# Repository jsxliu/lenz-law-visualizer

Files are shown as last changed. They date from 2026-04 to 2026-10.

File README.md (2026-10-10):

# Lenz’s Law Visualizers

**An open-source hardware initiative by [OpenApparatus](https://openapparatus.org/)**

Three classroom designs demonstrate eddy currents and magnetic braking. Each
includes printable parts, a materials list, photographs, physics-based animation, and assembly instructions.

## Choose a design

| Design | Published version | Description | Build guide and files |
| --- | --- | --- | --- |
| Dual-tube | v1 | Compare a magnet descending through copper tube with a control weight falling through a clear tube. | [View dual-tube design](designs/dual-tube-design/README.md) |
| Triple-tube | v1 | Compare a control weight in a clear tube with magnets descending through aluminum and copper tubes; the control falls fastest and the copper-tube magnet slowest. | [View triple-tube design](designs/triple-tube-design/README.md) |
| See-through | v1 | Watch a ring magnet and a nonmagnetic control ring descend around matching copper tubes inside clear tubes, making magnetic braking directly visible. | [View see-through design](designs/see-through-design/README.md) |

### Dual-tube visualizer

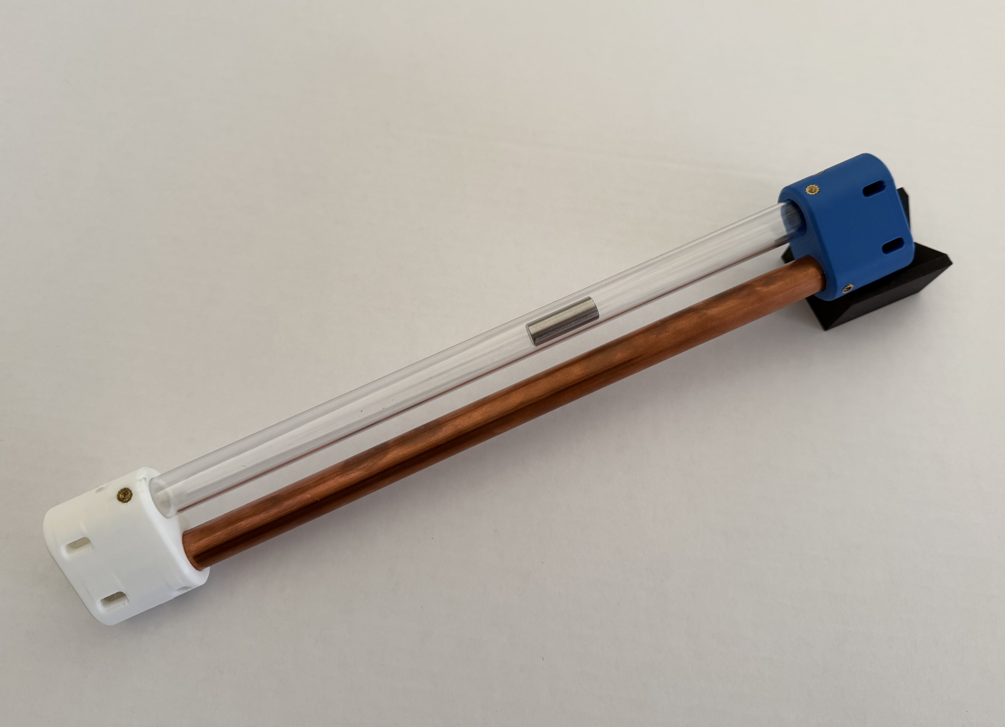
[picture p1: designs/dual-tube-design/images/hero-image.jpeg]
Dual-tube prototype


[Build guide and print files](designs/dual-tube-design/README.md).
Compares a magnet falling through a copper tube with a nonmagnetic control weight falling through a clear tube.

[Watch the animation (22.5 seconds)](https://jsxliu.github.io/lenz-law-visualizer/designs/dual-tube-design/animation/):
a real-time fall followed by a quarter-speed slow-motion replay.
The player includes a **Download video (MP4)** link.
See the [animation notes](designs/dual-tube-design/animation/README.md)
for its parameters, assumptions, and credits.

### Triple-tube visualizer

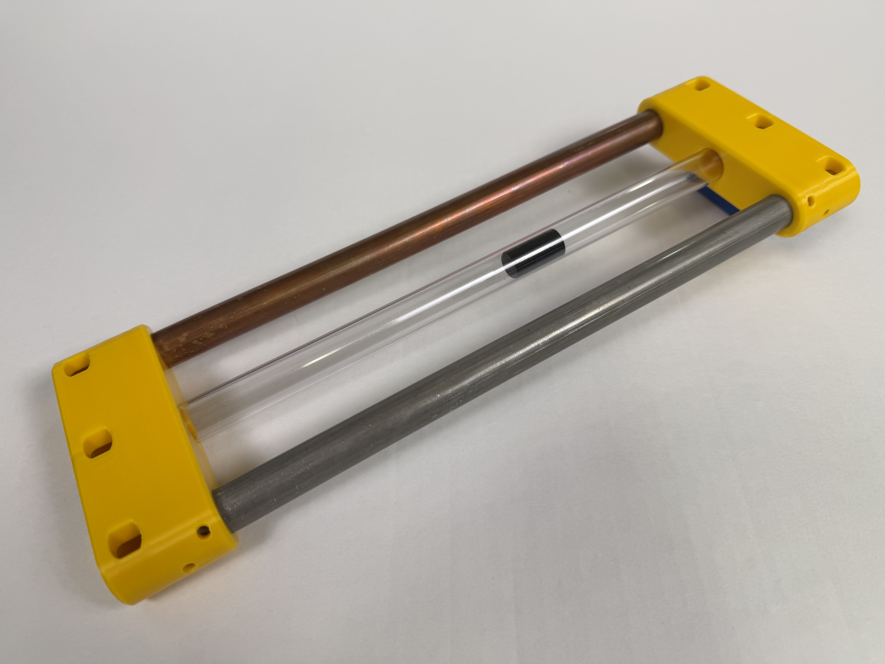
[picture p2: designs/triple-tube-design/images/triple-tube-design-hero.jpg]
Triple-tube prototype


[Build guide and print files](designs/triple-tube-design/README.md).
Adds an aluminum tube for comparison with the copper and clear tubes.

[Watch the animation (20.72 seconds)](https://jsxliu.github.io/lenz-law-visualizer/designs/triple-tube-design/animation/):
a simultaneous release in copper, clear, and aluminum tubes, followed by a
quarter-speed replay. The player includes a **Download video (MP4)** link.
See the [animation notes](designs/triple-tube-design/animation/README.md)
for its parameters, assumptions, and credits.

### See-through visualizer

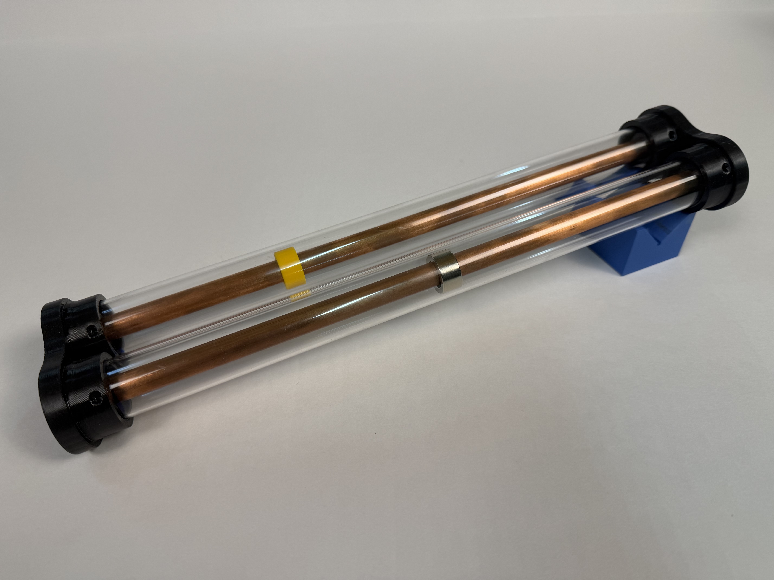
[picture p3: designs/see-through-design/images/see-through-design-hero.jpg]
See-through prototype


[Build guide and print files](designs/see-through-design/README.md).
Clear outer tubes keep the ring magnet and control ring enclosed and visible throughout their falls.

[Watch the animation (12.05 seconds)](https://jsxliu.github.io/lenz-law-visualizer/designs/see-through-design/animation/):
a real-time fall followed by a quarter-speed slow-motion replay.
The player includes a **Download video (MP4)** link.
See the [animation notes](designs/see-through-design/animation/README.md)
for its parameters, assumptions, and credits.

## Repository layout

```text
README.md                       Overview and design comparison
CITATION.cff                   Citation metadata for GitHub
LICENSE                         Shared hardware license
designs/
   dual-tube-design/
     README.md                  Existing design’s build guide
     animation/                 Video player, scenario, and credits
     parts/                     Printable STL files
     images/                    Prototype photograph
   triple-tube-design/
     README.md                  v1 build guide
     animation/                 Video player, scenario, and credits
     parts/                     Printable STL files
     images/                    Prototype photograph
   see-through-design/
     README.md                  v1 build guide
     animation/                 Video player, scenario, and credits
     parts/                     Printable STL files
     images/                    Prototype photograph
```

## Citation

Use GitHub’s **Cite this repository** menu or [CITATION.cff](CITATION.cff).
Include the design and version when citing a particular build, such as **Dual-Tube Design, v1**.

Suggested general citation:

> Liu, Jonathan. *Lenz’s Law Visualizers*. OpenApparatus, 2026. [https://github.com/jsxliu/lenz-law-visualizer](https://github.com/jsxliu/lenz-law-visualizer).

## License and attribution

- Hardware designs and build documentation: [CERN-OHL-W-2.0](LICENSE).
- Animation text, video, poster, and synthesized sound: [CC BY 4.0](designs/dual-tube-design/animation/LICENSE-media).
- Animation viewer: [MIT](designs/dual-tube-design/animation/LICENSE-viewer).

See the [dual-tube animation credits](designs/dual-tube-design/animation/credits.md),
[triple-tube animation credits](designs/triple-tube-design/animation/credits.md),
and [see-through animation credits](designs/see-through-design/animation/credits.md) for sources and attribution.

Created by Jonathan Liu. If you build from or adapt this project, please preserve attribution and clearly indicate your modifications.

## Community acknowledgements

Thank you to educators who tested beta builds, built their own versions, and
shared feedback, and to participants at Maker Faires, FAB26 in Boston, and
classroom and university mini-workshops. Their experiences help improve these designs.

## AI assistance

AI tools assisted with drafting documentation, refactoring code, and creating visuals. Jonathan Liu at OpenApparatus directs the project and retains responsibility for design decisions, physical testing, and published content.

## Get involved with OpenApparatus

* **Educators:** [Request a Beta-Test Donation](https://openapparatus.org/beta.html).
* **Students:** [Apply to Start a Chapter](https://forms.gle/mwWGrnZB5XusfW3L9).
* **Learn more:** Visit [openapparatus.org](https://openapparatus.org/).

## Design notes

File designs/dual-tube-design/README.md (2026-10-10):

# Dual-Tube Lenz's Law Visualizer

**An open-source hardware initiative by [OpenApparatus](https://openapparatus.org/)**

[← All designs](../../README.md)

**Status:** Public prototype · **Design version:** v1

As of September 2026, 20 beta units have been deployed to universities,
museums, and high schools across 13 states and 3 countries. Testing
includes a [4,000-cycle automated stress test](https://www.youtube.com/watch?v=3sY6RCX2NQ0)
using a motorized, Arduino-controlled rig.

A ruggedized, student-built, and user-friendly physics apparatus designed to safely visualize eddy currents and magnetic braking in a classroom setting.

When a permanent rare-earth magnet falls through the copper tube, the changing magnetic field induces massive eddy currents in the conductive wall through a small air gap. This creates an opposing magnetic force that acts as an "invisible parachute" or "invisible brake." Simultaneously, a non-magnetic control weight free-falls through a parallel clear polycarbonate tube, providing a real-time contrast in velocity. Builders can use either the original off-the-shelf 316 stainless steel dowel pin or the included 3D-printable control weight.

The control weight reaches the opposite end almost instantly, while the magnet's soft landing is dramatically delayed by several seconds due to the magnetic braking effect. Both descents can be confirmed visually through the 3D-printed slotted viewing windows, with the clear tube offering full visual acuity of the free-fall baseline.

Built entirely from easily sourced off-the-shelf hardware and two custom 3D-printed end caps, this kit is perfect for high school physics demonstrations, hands-on STEM outreach, electromagnetic modeling, and kinematics calculations.

I built this project as a high school junior to deepen my understanding of physics, practice hands-on design, and develop a clear way to communicate scientific ideas through hardware.

Prototype image

## Physics-based animation

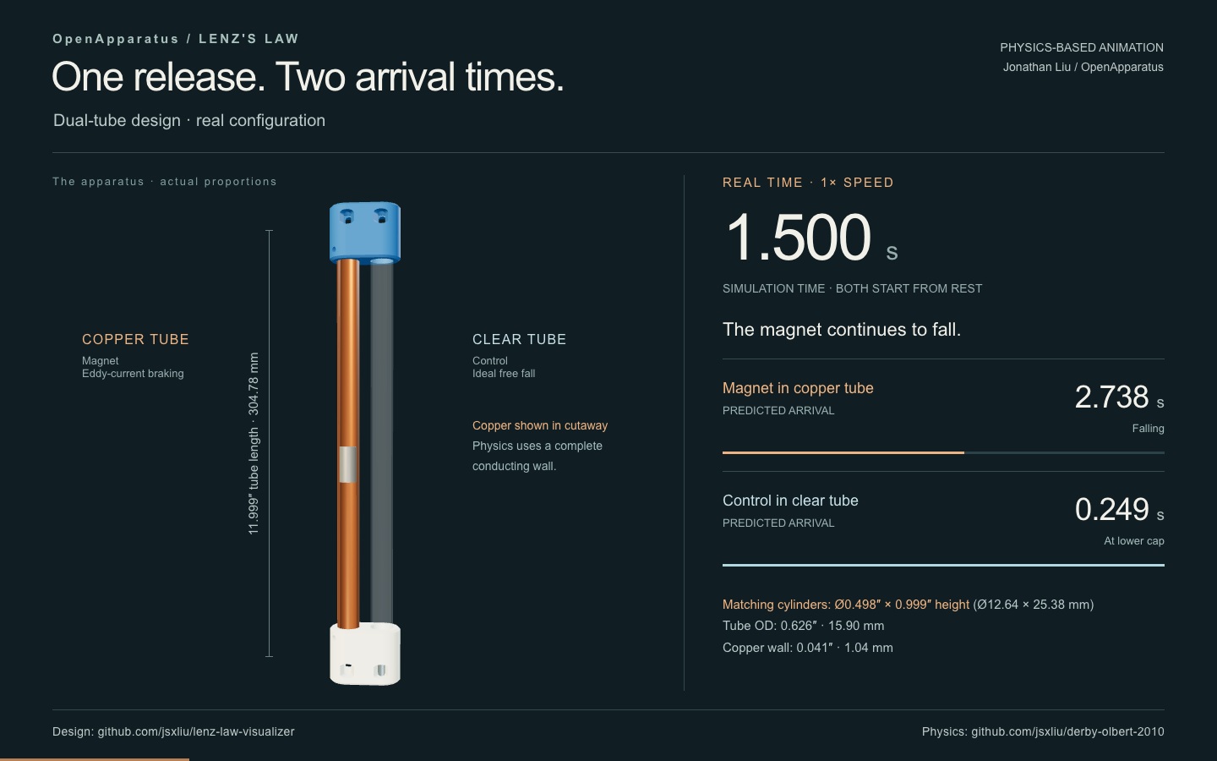
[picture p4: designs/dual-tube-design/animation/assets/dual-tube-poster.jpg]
Preview of the dual-tube physics-based animation


**[Watch the animation (22.5 seconds)](https://jsxliu.github.io/lenz-law-visualizer/designs/dual-tube-design/animation/)**

The player includes a **Download video (MP4)** link.

This fixed simulation serves as a first-order digital twin, showing a real-time
fall and quarter-speed replay. Calculations use the
[Derby–Olbert reproduction](https://github.com/jsxliu/derby-olbert-2010).
Predicted arrivals are **2.738 s** for the magnet and **0.249 s** for the control.
The copper cutaway is visual only; the modeled wall remains electrically intact.

The film represents one configuration; hardware dimensions and results can vary.
See its [parameters and assumptions](animation/scenario.md) and
[credits and licenses](animation/credits.md).

## Print files

* [cap_lenz_visualizer_v2.stl](parts/cap_lenz_visualizer_v2.stl) — 3D-printable end cap; print two
* [control_weight_cylinder_3D_print_v1.stl](parts/control_weight_cylinder_3D_print_v1.stl) — Optional 3D-printable control weight; print one

## Safety

* **Captive System:** The end caps and fasteners keep the magnet and control weight enclosed, reducing shatter, impact, and pinch hazards. Inspect the caps, tubes, inserts, and fasteners before every demonstration, and do not use the apparatus if any part is cracked, loose, or damaged.
* **Strong Magnets:** Keep the apparatus away from implanted medical devices, magnetic storage, electronics, and ferromagnetic objects. Follow the magnet manufacturer’s handling and separation guidance.
* **Pinch, Impact, and Shatter Hazards:** Keep fingers and loose metal objects away from the magnet. Do not use a cracked or chipped magnet.
* **Hot Surfaces & Sharp Edges:** Assembly requires a soldering iron and mechanical cutting tools. Wear appropriate protection and handle hot tools and metal edges carefully.
* **Supervision:** Assemble and operate the apparatus under qualified adult supervision.

## Bill of materials (per kit)

**Hardware:**

* 1x Copper Tube: Nominal 1/2-inch Type L or Type M, with a 5/8-inch outside diameter, cut to 12 inches. See the [Copper Tube Handbook](https://www.copper.org/publications/pub_list/pdf/copper_tube_handbook.pdf) for standard dimensions.
* 1x Clear Tube: Polycarbonate, 5/8" OD x 1/2" ID x 1/16" Wall, cut to 12 inches.
* 1x Magnet: Neodymium Cylinder, 1/2" Nominal Diameter x 1.00" Height.
* 1x Control Weight — choose one option:
  * **Off-the-shelf:** 316 stainless steel dowel pin matching the nominal size of the magnet.
  * **3D-printed:** Print [control_weight_cylinder_3D_print_v1.stl](parts/control_weight_cylinder_3D_print_v1.stl).

**Fasteners (For 2 End Caps):**

* 6x Ruthex M3 Threaded Inserts (RX-M3x5x4 Brass Heat-Set).
* 6x M3-0.5 x 5mm Hex Socket Set Screws (Cup Point).

**3D-Printed Parts:**

* 2x End Caps: Print [cap_lenz_visualizer_v2.stl](parts/cap_lenz_visualizer_v2.stl).
* 1x Control Weight (optional): Print [control_weight_cylinder_3D_print_v1.stl](parts/control_weight_cylinder_3D_print_v1.stl) instead of using the stainless steel dowel pin.

## Print settings (PETG recommended)

**End Caps:**

* **Wall loops:** 6.
* **Strength - Sparse Infill:** 18% density, gyroid pattern.

**3D-Printed Control Weight:**

* **Strength - Sparse Infill Density:** 100%.
* **Strength - Sparse Infill Pattern:** Rectilinear.

## Assembly

**Required Tools & Accessories:**

* Tubing Cutter (Suitable for copper and plastic)
* Reaming Pen / Deburring Tool
* Soldering Iron for Heat-Set Inserts
* Loctite 242 (Blue Removable Threadlocker)
* Metric Hex Key (For M3 set screws)
* Caliper and Tape Measure

**Assembly Steps:**

1. **Prepare the Tubes:** Cut both the copper and polycarbonate tubes to exactly 12 inches in length. Use the reaming pen to thoroughly deburr the inside and outside edges of all cut ends.
2. **Check Free Travel:** Over a padded surface, pass the magnet through the copper tube and the selected control weight through the clear tube. Confirm that both objects travel from end to end without binding.
3. **Install the Inserts:** Temporarily seat the copper tube in its socket so it acts as a depth stop for the adjacent inserts. Using the soldering iron, gently heat-set three brass inserts into each end cap until they are flush with the plastic. Keep the inserts perpendicular to the cap surface, use the correct tool temperature for the selected filament, and remove the temporary tube after the inserts and surrounding plastic have cooled completely.
4. **Seat the Tubes:** Insert the copper and polycarbonate tubes into the bottom end cap until both meet their internal stops. The cavities are asymmetric to account for material tolerances: the copper tube seats in the tighter cavity and the polycarbonate tube in the looser cavity. Do not force the polycarbonate tube into the tighter cavity.
5. **Load the Weights:** Place the permanent magnet in the copper tube and the selected control weight—the stainless steel dowel pin or the 3D-printed cylinder—in the polycarbonate tube. Use one control-weight option, not both.
6. **Cap the System:** Align the asymmetric sockets and press the second end cap fully onto both tubes. Do not invert the apparatus until both caps have been fastened.
7. **Secure the Assembly:** Install three set screws in each end cap against the copper tube. Apply a small amount of Loctite 242 to the screw threads and tighten the screws evenly until snug. Do not overtighten or deform the copper tube. No set screws should contact the polycarbonate tube.
8. **Allow the Threadlocker to Cure:** Leave the assembly undisturbed for at least 24 hours at room temperature, or longer if required by the threadlocker manufacturer for the working conditions.
9. **Inspect the Captive System:** Confirm that all six set screws are secure, both caps are fully seated, and neither falling object can leave the apparatus.
10. **Perform the Function Check:** Over a padded surface, flip the secured apparatus several times. Confirm that the magnet and control weight travel from end to end without binding.

## Version

* **v1** — Initial public prototype release, as documented in the original README.

The existing end-cap STL filename includes `v2` and has been preserved for traceability. The printable control-weight STL was added as an alternative to the original off-the-shelf stainless steel dowel pin. These file changes do not establish a new hardware revision.

## License and attribution

The hardware design and this build guide retain the **CERN Open Hardware
Licence Version 2 - Weakly Reciprocal (CERN-OHL-W-2.0)**. See the
[repository LICENSE](../../LICENSE) for the full license text.

The animation's original text, video, poster, and synthesized sound are licensed
under [CC BY 4.0](animation/LICENSE-media); its HTML/CSS viewer is
[MIT licensed](animation/LICENSE-viewer).
See the [component credits](animation/credits.md).

Created by Jonathan Liu. If you build from or adapt this project, please preserve attribution and clearly indicate your modifications.

## 📝 Notes
This repository is meant to document an authentic learning and design process. The project may evolve over time as testing, classroom use, and fabrication experience lead to improvements.

## 🌍 Get Involved with OpenApparatus

This repository is maintained by the **OpenApparatus** engineering team. We are dedicated to removing the financial barriers to advanced physics and engineering education.

* **Educators:** Want to deploy this hardware in your classroom? [Request a Beta-Test Donation](https://openapparatus.org/beta.html).
* **Students:** Want to manufacture these kits for underfunded schools in your area? [Apply to Start a Chapter](https://forms.gle/mwWGrnZB5XusfW3L9).
* **Learn More:** Visit [openapparatus.org](https://openapparatus.org/) to see our full library of open-source STEM modules and our latest deployment impact metrics.

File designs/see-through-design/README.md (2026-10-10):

# See-Through Lenz’s Law Visualizer

**An open-source hardware initiative by [OpenApparatus](https://openapparatus.org/)**

[← All designs](../../README.md)

The see-through visualizer makes magnetic braking directly visible. A ring magnet falls around a copper tube, enclosed by a clear polycarbonate tube.

Two parallel drop paths use matching copper and polycarbonate tubes. One contains the ring magnet; the other contains a nonmagnetic, 3D-printed control weight with the same ring geometry.

The moving magnet induces eddy currents in the copper wall. Their magnetic field opposes its motion, slowing its descent. The printed ring provides a free-fall reference, and both descents remain visible through the clear tubes.

Two 3D-printed end caps hold the tubes. Epoxy bonds the polycarbonate tubes to the caps; the copper tubes sit in unbonded sockets.

See-through prototype

## Physics-based animation

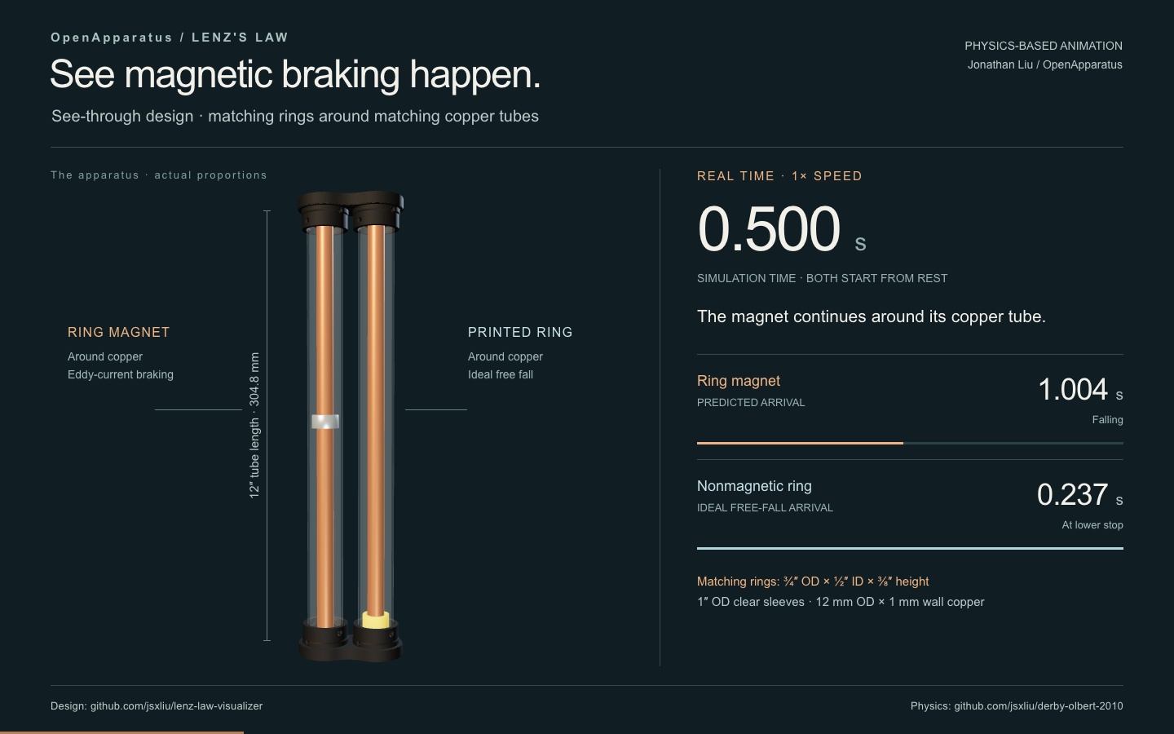
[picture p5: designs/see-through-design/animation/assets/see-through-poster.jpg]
Preview of the see-through physics-based animation


**[Watch the animation (12.05 seconds)](https://jsxliu.github.io/lenz-law-visualizer/designs/see-through-design/animation/)**

The player includes a **Download video (MP4)** link.

The existing-size ring magnet and matching nonmagnetic control are released
simultaneously, shown at real time and replayed at quarter speed. Predicted
arrivals are **1.004 s** for the magnet and **0.237 s** for the control. The simulation adapts
the cylindrical-magnet field from the
[Derby–Olbert reproduction](https://github.com/jsxliu/derby-olbert-2010)
to the ring geometry; the control follows analytic free fall.

See the [parameters and assumptions](animation/scenario.md) and
[credits and licenses](animation/credits.md).

## 📁 Overview

This folder contains the prototype photograph, two printable STL files, a physics-based animation, and build guidance for the see-through design.

**Included files:**

* [animation/](animation/README.md) — Video player, MP4, scenario, and credits

* [see-through-design-hero.jpg](images/see-through-design-hero.jpg) — Prototype photograph
* [see_through_design_end_cap_v1.stl](parts/see_through_design_end_cap_v1.stl) — See-through end cap; print two
* [free_fall_ring_v1.stl](parts/free_fall_ring_v1.stl) — Ring-shaped control weight; print one
* `README.md` — Project overview, safety notes, and build guidance

## 💡 Motivation

I enjoy building physical models that make abstract science ideas easier to see and explain. This project combines physics, mechanical design, 3D printing, and technical communication. The see-through variation addresses the limited visibility of a magnet inside an opaque conducting tube by moving a ring magnet around the outside of the conductor.

## ⚠️ Safety & Liability

* **Captive system:** The end caps and cured adhesive joints keep the falling objects enclosed. Inspect the caps, tubes, and adhesive joints before every demonstration. Do not use the apparatus if any part is cracked, loose, displaced, or damaged.
* **Strong magnets:** Keep the apparatus away from implanted medical devices, magnetic storage, electronics, and ferromagnetic objects. Follow the magnet manufacturer’s handling and separation guidance.
* **Adhesives and chemical exposure:** Avoid skin and eye contact with uncured resin, hardener, and mixed epoxy. Wear gloves compatible with the selected product, safety goggles, and protective clothing. Perform syringe injection in a well-lit, well-ventilated workspace with a protected work surface, separated from bystanders. Follow the product’s Safety Data Sheet for handling, cleanup, disposal, and first aid.
* **Supervision:** Assemble and operate the apparatus under qualified adult supervision.

## 🛠️ Bill of Materials (Per Kit)

### Hardware

* 2x Inner Copper Tubes: Matching tubes, each with a 12 mm outside diameter and 1 mm wall thickness (10 mm calculated inside diameter). Choose stock at least as long as the actual polycarbonate tubes, then trim to match their length.
* 2x Outer Clear Tubes: Matching polycarbonate tubes, each with a 0.87-inch inside diameter, 1-inch outside diameter, and nominal 12-inch length. Each surrounds an inner copper tube and a falling ring.
* 1x Magnet: Permanent ring magnet (annular cylinder), with a 1/2-inch inside diameter, 3/4-inch outside diameter, and 3/8- inch height.
* 1x Control Weight: Nonmagnetic, 3D-printed ring cylinder with the same geometry as the magnet: 1/2-inch inside diameter, 3/4-inch outside diameter, and 3/8-inch height.

**Why 12 mm copper OD:** The magnet’s 1/2-inch (12.7-mm) inside diameter limits the copper-tube outside diameter. The selected maximum OD for this design is **12 mm**, leaving 0.7 mm diametral clearance, or a nominal **0.35 mm radial gap** when centered. The magnet’s terminal velocity and resulting drop time depend strongly on this gap. The 12-mm OD keeps the gap small while providing clearance for free sliding.

**Tube lengths:** 12-inch is exactly **304.8-mm**, not 300-mm. Tubes listed online as 300-mm may arrive as exact 12-inch lengths; measure the actual tubes before cutting. Both polycarbonate tubes must have the same length, and both copper tubes must match that measured length. If a copper tube is too short, obtain longer stock.

### Adhesives

* **Epoxy:** [WEST SYSTEM G/flex 650 Toughened Epoxy](https://www.westsystem.com/products/g-flex-650-toughened-epoxy/). Mix resin and hardener thoroughly **1:1 by volume**.
* **Application:** Bond the four polycarbonate-to-end-cap joints. The copper tubes remain seated without adhesive.
* **Cure:** Keep the assembly supported and undisturbed for at least **24 hours at 72°F (22°C)** after the final injection before handling or use. Allow longer cure time in cooler conditions.

Follow the manufacturer’s [application instructions](https://www.westsystem.com/app/uploads/2022/12/650-K-Aluminum-Kit-Instruction.pdf) and [resin and hardener Safety Data Sheets](https://www.westsystem.com/safety/safety-data-sheets/).

### 3D-Printed Parts

* 2x See-Through End Caps: Each locates the two inner copper tubes and two outer polycarbonate tubes and includes the adhesive injection and vent ports. **Print file:** [see_through_design_end_cap_v1.stl](parts/see_through_design_end_cap_v1.stl).
* 1x Ring-Shaped Control Weight: Match the magnet’s inside diameter, outside diameter, and height for a fair comparison. Confirm that the printed ring slides freely around its copper tube and inside its clear tube. **Print file:** [free_fall_ring_v1.stl](parts/free_fall_ring_v1.stl).

## 🖨️ 3D-Printer Settings (PETG Starting Material)

Use these settings as a starting point for the included STL files. Check the printed parts’ fit and the filament’s compatibility with the epoxy before assembly.

**End Caps — Starting Settings:**

* **Strength — Wall Loops:** 6
* **Strength — Sparse Infill:** 18% density, gyroid pattern

**3D-Printed Ring Control Weight:**

* **Strength — Sparse Infill Density:** 100%
* **Strength — Sparse Infill Pattern:** Rectilinear

## ⚙️ Assembly Procedure

**Required Tools & Accessories:**

* Copper tube cutter and, if needed, a cutting tool suitable for polycarbonate
* Reaming pen or deburring tool
* Caliper and tape measure
* Epoxy mixing cups and stirrers
* Glue applicator syringe with a blunt-tip needle, sealing cap, and dispensing tips, used to inject the mixed epoxy into the end-cap ports
* Product-compatible protective gloves, safety goggles, and protective clothing
* Protected work surface and supports that maintain tube and cap alignment during curing

**Assembly Steps:**

1. **Prepare the tubes:** Measure both polycarbonate tubes and confirm they are the same length. Use that actual length as the reference for both copper tubes. If a copper tube is longer, use a copper tube cutter to trim it to match; replace any copper tube that is too short with longer stock. Use a deburring tool to clean the inside and outside edges of cut or rough tube ends as needed, remove debris, and confirm all four tubes have the same final length. Prepare the bonding surfaces according to the adhesive manufacturer’s instructions for each material.
2. **Print and inspect the parts:** Print two end caps and one ring-shaped control weight. Reject parts with cracks, weak layers, obstructed sockets, or malformed injection and vent ports. Remove rough edges and debris from the control weight’s travel surfaces.
3. **Check the individual travel paths:** Slide the ring magnet around one copper tube and the control weight around the other. Check each inside its polycarbonate outer tube. Both rings must travel freely without catching on the copper, clear tube, or end-cap seating surfaces.
4. **Seat the first cap:** Insert both inner copper tubes into their sockets in one end cap. Seat the matching outer polycarbonate tube around each copper tube. Keep each pair concentric and fully seated against its designated stops.
5. **Load the falling objects:** Slide the ring magnet over the copper tube in one path and the printed ring control weight over the copper tube in the other. Keep each object inside its outer polycarbonate tube.
6. **Fit the second cap:** Align the inner and outer sockets and place the second end cap onto all four tubes. Confirm that every tube remains fully seated and that both paths stay aligned.
7. **Perform the initial function check:** With both unbonded caps held together using both hands, gently flip the apparatus several times. Confirm that the magnet and control weight both travel smoothly from end to end.
8. **Prepare for adhesive injection:** Set up the well-lit, well-ventilated workspace, put on the required gloves and goggles, and support the aligned assembly. Identify the injection and vent ports for each local tube-to-cap joint. Prepare and load the epoxy according to its specified mix ratio and working time.
9. **Inject and distribute epoxy at one joint:** Orient the joint so its injection port is below its vent port. Inject slowly through the lower port until epoxy first appears at the upper vent. Stop before excess adhesive enters the falling path. While the epoxy is workable, gently rotate the polycarbonate tube within its socket to help distribute adhesive around the bonding interface, without unseating the tube or disturbing alignment. Rotation helps distribute adhesive; the socket geometry controls the bond gap.
10. **Repeat at the remaining joints:** Repeat the injection and distribution process for the other three outer-polycarbonate-to-cap joints, covering both ends of both clear tubes. Keep all tubes seated. Complete any rotation before the epoxy at either end of that tube begins to set; then leave the tube undisturbed. The inner copper tubes remain captured in their sockets; do not inject adhesive into their seats or the rings’ travel paths.
11. **Allow the adhesive to cure:** Keep the assembly supported and undisturbed for at least 24 hours at 72°F (22°C) after the final injection; allow longer in cooler conditions. Follow the cure guidance in [Adhesives](#adhesives).
12. **Inspect and perform the final function check:** Once full cure is complete, inspect every bond, tube seat, and cap. Confirm that the copper tubes are retained, neither cap can separate during normal operation, and no adhesive obstructs either ring’s travel. Manually turn the completed apparatus over several times and confirm that both objects still travel smoothly.

## 🔬 Use and Expected Observations

Move both falling objects to the same end of the completed apparatus. Turn it over to release them together and observe both rings through the clear polycarbonate tubes.

* **Control path:** The nonmagnetic, printed ring falls quickly, providing the free-fall reference.
* **Magnet path:** The ring magnet falls more slowly because its motion induces eddy currents in the inner copper tube.

Both rings remain visible throughout their descent. Mechanical friction effects are usually negligible in this type of setting and design.

## 📄 License

This project is licensed under the **CERN Open Hardware Licence Version 2 – Weakly Reciprocal (CERN-OHL-W-2.0)**. Please see the [repository LICENSE](../../LICENSE) file for the full license text.

The animation text, video, poster, and synthesized landing sounds use
[CC BY 4.0](animation/LICENSE-media); the viewer uses
[MIT](animation/LICENSE-viewer). See [component credits](animation/credits.md).

## ✍️ Attribution

Created by Jonathan Liu. If you build from or adapt this project, please preserve attribution and clearly indicate your modifications.

## 📝 Notes

This repository documents an authentic learning and design process. The project may evolve as testing, classroom use, and fabrication experience lead to improvements.

## 🌍 Get Involved with OpenApparatus

This repository is maintained by the **OpenApparatus** engineering team. We are dedicated to removing financial barriers to advanced physics and engineering education.

* **Educators:** Want to deploy this hardware in your classroom? [Request a Beta-Test Donation](https://openapparatus.org/beta.html).
* **Students:** Want to manufacture these kits for underfunded schools in your area? [Apply to Start a Chapter](https://forms.gle/mwWGrnZB5XusfW3L9).
* **Learn more:** Visit [openapparatus.org](https://openapparatus.org/) to see our full library of open-source STEM modules and latest deployment impact metrics.

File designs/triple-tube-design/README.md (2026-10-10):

# Triple-Tube Lenz’s Law Visualizer

**An open-source hardware initiative by [OpenApparatus](https://openapparatus.org/)**

[← All designs](../../README.md)

**Release:** v1

The triple-tube visualizer extends the dual-tube design with an aluminum tube so students can compare how conductor material affects magnetic braking. It has three parallel drop paths: a control weight in the clear polycarbonate tube, one permanent magnet in the aluminum tube, and one permanent magnet in the copper tube.

When all three objects are released together, the control weight falls fastest. The magnet in the aluminum tube falls more slowly, and the magnet in the copper tube falls slowest.

As a magnet moves through a conductive tube, its changing magnetic field induces eddy currents in the tube wall. Those currents create a magnetic field that opposes the magnet’s motion. Copper produces a stronger braking effect than aluminum in this apparatus, making the effect of material conductivity visible in a single demonstration.

The triple-tube and dual-tube designs share component specifications wherever practical. The triple-tube version adds an aluminum comparison tube and redesigned end caps that hold all three tubes.

Triple-tube prototype

## Physics-based animation

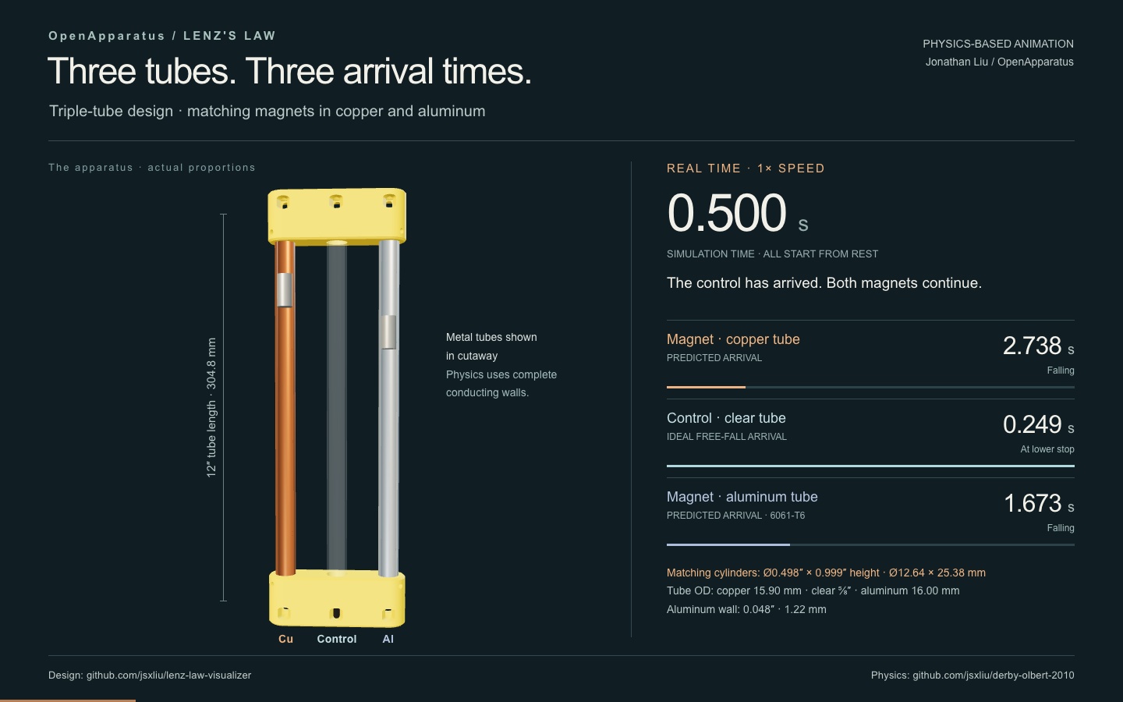
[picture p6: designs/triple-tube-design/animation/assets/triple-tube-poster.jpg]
Preview of the triple-tube physics-based animation


**[Watch the animation (20.72 seconds)](https://jsxliu.github.io/lenz-law-visualizer/designs/triple-tube-design/animation/)**

The player includes a **Download video (MP4)** link.

The three weights release together; a real-time fall is followed by a
quarter-speed replay. Copper and aluminum trajectories use the same
[Derby–Olbert reproduction](https://github.com/jsxliu/derby-olbert-2010)
as the dual-tube animation, while the control follows ideal free fall.
Predicted arrivals are **0.249 s** for the control, **1.673 s** for the
aluminum magnet, and **2.738 s** for the copper magnet. The metal cutaways
are visual only; the modeled tube walls remain electrically intact.

The movie uses the physics report’s aluminum geometry at a 12-inch length:
**16.00 mm OD × 13.56 mm ID × 1.22 mm wall**
(approximately **0.630″ OD × 0.534″ ID × 0.048″ wall**).

See the [parameters and assumptions](animation/scenario.md) and
[credits and licenses](animation/credits.md).

## 📁 Overview

This folder contains the prototype photograph, printable parts, a physics-based animation, and build documentation for the triple-tube design.

**Included files:**

* [cap_triple_tube_design_v1.stl](parts/cap_triple_tube_design_v1.stl) — Triple-tube end cap; print two
* [control_weight_cylinder_3D_print_v1.stl](parts/control_weight_cylinder_3D_print_v1.stl) — Optional 3D-printable control weight; print one
* [triple-tube-design-hero.jpg](images/triple-tube-design-hero.jpg) — Prototype photograph
* [animation/](animation/README.md) — Physics-based video, player, scenario, and credits
* `README.md` — Project overview, safety notes, and build guidance

## 💡 Motivation

I enjoy building physical models that make abstract science ideas easier to see and explain. This project combines physics, mechanical design, 3D printing, and technical communication. It is part of my broader interest in using hardware to turn mathematical and physical concepts into tangible learning experiences.

## ⚠️ Safety & Liability

* **Captive system:** The end caps and fasteners keep the magnets and control weight enclosed. Inspect the caps, tubes, inserts, and fasteners before every demonstration, and do not use the apparatus if any part is cracked, loose, or damaged.
* **Strong magnets:** Keep the apparatus away from implanted medical devices, magnetic storage, electronics, and ferromagnetic objects. Follow the magnet manufacturer’s handling and separation guidance.
* **Pinch, impact, and shatter hazards:** Keep fingers and loose metal objects away from the magnets. Do not use cracked or chipped magnets.
* **Hot surfaces and sharp edges:** Assembly requires cutting and deburring tubes and heat-setting threaded inserts. Wear appropriate protection and handle cutting tools, hot tools, and metal edges carefully.
* **Supervision:** Assemble and operate the apparatus under qualified adult supervision.

## 🛠️ Bill of Materials (Per Kit)

### Hardware

* 1x Copper Tube: Nominal 1/2-inch Type L or Type M copper tube, actual OD approximately 5/8 inch, cut to 12 inches.
* 1x Clear Tube: Polycarbonate, 5/8-inch OD × 1/2-inch ID × 1/16-inch wall, cut to 12 inches.
* 1x Aluminum Tube: 6061-T6 drawn aluminum round tube, 5/8-inch OD × 0.035-inch wall × 0.555-inch ID, cut to 12 inches.
* 2x Magnets: Neodymium cylinders, nominal 1/2-inch diameter × 1 inch long. Use two magnets with matching dimensions and magnetic properties.
* 1x Control Weight — choose one option:
  * **Off-the-shelf:** 316 stainless steel dowel pin matching the nominal size of the magnet.
  * **3D-printed:** Print [control_weight_cylinder_3D_print_v1.stl](parts/control_weight_cylinder_3D_print_v1.stl).

### Fasteners

The triple-tube design uses the same fastener specifications as the [dual-tube design](../dual-tube-design/README.md), with twice the quantity of inserts and set screws:

* 12x Ruthex M3 threaded inserts, RX-M3x5x4 brass heat-set type.
* 12x M3-0.5 × 5 mm hex socket set screws, cup point.
* Loctite 242 blue removable threadlocker, as needed.

### 3D-Printed Parts

* 2x Triple-Tube End Caps: Print [cap_triple_tube_design_v1.stl](parts/cap_triple_tube_design_v1.stl).
* 1x Control-Weight Cylinder (optional): Print [control_weight_cylinder_3D_print_v1.stl](parts/control_weight_cylinder_3D_print_v1.stl) instead of using the stainless steel dowel pin.

## 🖨️ 3D-Printer Settings (PETG Filament Recommended)

The triple-tube and dual-tube designs use the same printing approach:

**End Caps:**

* **Strength — Wall Loops:** 6
* **Strength — Sparse Infill:** 18% density, gyroid pattern

**3D-Printed Control Weight:**

* **Strength — Sparse Infill Density:** 100%
* **Strength — Sparse Infill Pattern:** Rectilinear

The control weight has a small print volume, so 100% rectilinear infill is recommended.

## ⚙️ Assembly Procedure

**Required Tools & Accessories:**

* Tube-cutting tools suitable for copper, aluminum, and polycarbonate
* Reaming pen or deburring tool
* Soldering iron or heat-insert tool
* Metric hex key for M3 set screws
* Caliper and tape measure
* Loctite 242 blue removable threadlocker

**Assembly Steps:**

1. **Prepare the tubes:** Cut the copper, polycarbonate, and aluminum tubes to 12 inches. Deburr the inside and outside edges of every cut end.
2. **Check free travel:** Over a padded surface, pass each magnet through its metal tube and the selected control weight through the clear tube. Confirm that every object travels from end to end without binding.
3. **Print and inspect the parts:** Print two triple-tube end caps and, if selected, one control-weight cylinder. Reject parts with cracks, weak layers, obstructed sockets, or malformed fastener holes.
4. **Install the inserts:** Temporarily seat the matching copper or aluminum tube in each outer socket so the tube acts as a depth stop for the adjacent inserts. Heat-set six threaded inserts squarely into each end cap until they are flush with the plastic. Use the correct tool temperature for the selected filament. Remove each temporary tube after the inserts and surrounding plastic have cooled completely, then allow the installed inserts to remain unloaded overnight before continuing.
5. **Seat the tubes:** Insert the copper and aluminum tubes into the two outer sockets and the clear polycarbonate tube into the center socket of the bottom cap. Seat all three tubes against their internal stops.
6. **Load the falling objects:** Place one matching magnet in the copper tube, the other matching magnet in the aluminum tube, and the selected control weight—the stainless steel dowel pin or the 3D-printed cylinder—in the clear tube. Use one control-weight option, not both.
7. **Fit the second cap:** Align the sockets and press the second end cap fully onto all three tubes. Do not invert the apparatus until both caps have been fastened.
8. **Secure the assembly:** Install six set screws in each end cap: three against the copper tube and three against the aluminum tube. Apply a small amount of removable threadlocker to the screw threads and tighten the screws evenly until snug. Do not overtighten or deform the tube walls.
9. **Allow the threadlocker to cure:** Leave the assembly undisturbed for at least 24 hours at room temperature, or longer if required by the threadlocker manufacturer for the working conditions.
10. **Inspect the captive system:** Confirm that all 12 set screws are secure, both caps are fully seated, and none of the falling objects can leave the apparatus.
11. **Perform the function check:** Over a padded surface, flip the secured apparatus several times. Confirm that both magnets and the control weight travel from end to end without binding.

The apparatus is ready for its comparative drop demonstration after the retention and function checks pass.

## 🔬 Use and Expected Observations

Move all three falling objects to the same end of the apparatus. Turn the apparatus over to release them together and observe their relative descent times.

The observed fastest-to-slowest order is:

1. **Clear tube:** The control weight falls fastest, providing the free-fall reference.
2. **Aluminum tube:** The magnet falls more slowly because of eddy-current braking.
3. **Copper tube:** The magnet falls slowest because copper produces the strongest braking effect in this apparatus.

This single action shows both the contrast between free fall and magnetic braking and the effect of conductor material on falling speed.

## 📌 Versioning

**v1 — Initial public release.** The release tag is `triple-tube-design-v1`, and the end-cap filename uses the same v1 design identifier.

## 📄 License

This project is licensed under the **CERN Open Hardware Licence Version 2 – Weakly Reciprocal (CERN-OHL-W-2.0)**. Please see the [repository LICENSE](../../LICENSE) file for the full license text.

The animation has separate [media](animation/LICENSE-media) and
[viewer](animation/LICENSE-viewer) licenses; see its [credits](animation/credits.md).

## ✍️ Attribution

Created by Jonathan Liu. If you build from or adapt this project, please preserve attribution and clearly indicate your modifications.

## 📝 Notes

This repository documents an authentic learning and design process. The project may evolve as testing, classroom use, and fabrication experience lead to improvements.

## 🌍 Get Involved with OpenApparatus

This repository is maintained by the **OpenApparatus** engineering team. We are dedicated to removing financial barriers to advanced physics and engineering education.

* **Educators:** Want to deploy this hardware in your classroom? [Request a Beta-Test Donation](https://openapparatus.org/beta.html).
* **Students:** Want to manufacture these kits for underfunded schools in your area? [Apply to Start a Chapter](https://forms.gle/mwWGrnZB5XusfW3L9).
* **Learn more:** Visit [openapparatus.org](https://openapparatus.org/) to see our full library of open-source STEM modules and latest deployment impact metrics.

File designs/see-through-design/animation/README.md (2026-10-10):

# See-through animation

[← See-through design and build guide](https://github.com/jsxliu/lenz-law-visualizer/tree/main/designs/see-through-design)

**[Watch the animation (12.05 seconds)](https://jsxliu.github.io/lenz-law-visualizer/designs/see-through-design/animation/)**

The player includes a **Download video (MP4)** link.

A ring magnet falls **around the outside of a copper tube**, beside a matching
nonmagnetic control ring. Both paths have the same copper tube and clear outer
sleeve. The simultaneous release is shown at real time and replayed at quarter
speed. Predicted arrivals are **1.004 s** for the magnet and **0.237 s** for the
free-fall control. Landing sounds are illustrative contact cues.

The apparatus view shows black upper and lower caps, a yellow control ring,
and dimensions in inches and millimeters.

This fixed simulation uses the prototype's **¾″ OD × ½″ ID × ⅜″ high ring**,
**12 mm OD × 1 mm wall copper**, and **12″ tube length**. The simulation adapts
the cylindrical-magnet field from the
[Derby–Olbert reproduction](https://github.com/jsxliu/derby-olbert-2010)
to the ring geometry and calculates its motion, including finite tube ends
and copper wall thickness. The control follows analytic free fall.

- [Simulation parameters and assumptions](scenario.md)
- [Credits and licenses](credits.md)

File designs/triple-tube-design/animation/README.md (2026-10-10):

# Triple-tube animation

[← Triple-tube design and build guide](https://github.com/jsxliu/lenz-law-visualizer/tree/main/designs/triple-tube-design)

**[Watch the animation (20.72 seconds)](https://jsxliu.github.io/lenz-law-visualizer/designs/triple-tube-design/animation/)**

The player includes a **Download video (MP4)** link.

Two matching cylindrical magnets fall inside **copper and aluminum tubes**,
beside a matching nonmagnetic control in a clear tube. All three objects are
released together. The descent is shown at real time and replayed at quarter
speed; landing sounds are illustrative contact cues.

Predicted arrivals are **0.249 s** for the control, **1.673 s** for the
aluminum magnet, and **2.738 s** for the copper magnet.

The apparatus view shows yellow upper and lower caps, a clear center tube,
and dimensions in inches and millimeters.

This fixed simulation uses the existing design's nominal **½″ diameter × 1″
long magnets** and **12″ tubes**. Copper uses the dual-tube film's specified
dimensions. Aluminum uses the physics report's **16.00 mm OD × 1.22 mm wall**
(**0.62992″ OD × 0.04803″ wall**), with a 13.56 mm bore. This simulation
overrides the build guide's ⅝″ OD × 0.035″ wall aluminum stock; nominal
conductivity remains 25 MS/m. The
[Derby–Olbert reproduction](https://github.com/jsxliu/derby-olbert-2010)
calculates both magnet trajectories with a finite tube length and the field
evaluated at the mean wall radius. The control follows analytic free fall.

The metal cutaways reveal the magnets; the physics assumes continuous,
electrically intact tube walls. These are predictions using nominal material
properties and centered motion, rather than measurements of the assembled kit.

- [Simulation parameters and assumptions](scenario.md)
- [Credits and licenses](credits.md)

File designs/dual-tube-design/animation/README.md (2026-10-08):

# Dual-tube animation

[← Dual-tube design and build guide](https://github.com/jsxliu/lenz-law-visualizer/tree/main/designs/dual-tube-design)

**[Watch the animation (22.5 seconds)](https://jsxliu.github.io/lenz-law-visualizer/designs/dual-tube-design/animation/)**

The player includes a **Download video (MP4)** link.

The magnet and control are released together, shown at real time and replayed at
quarter speed. Predicted arrivals are **2.738 s** for the magnet and **0.249 s**
for the control. Landing sounds mark each arrival; the control weight landing is louder.

The apparatus view shows blue upper and off-white lower caps, and dimensions in inches and millimeters.

This fixed simulation predicts the falls from nominal material properties using the
[Derby–Olbert reproduction](https://github.com/jsxliu/derby-olbert-2010).

- [Simulation parameters and assumptions](scenario.md)
- [Credits and licenses](credits.md)

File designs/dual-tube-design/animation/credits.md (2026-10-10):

# Animation credits and licenses

© 2026 Jonathan Liu / OpenApparatus.

See the project-wide [AI assistance](../../../README.md#ai-assistance).

## Presentation

Original text, video, poster, and synthesized landing sounds:
[CC BY 4.0](LICENSE-media). Viewer HTML/CSS:
[MIT](LICENSE-viewer). The sounds are illustrative contact cues, not measured acoustics.

Suggested attribution:

> “Dual-tube animation” by Jonathan Liu / OpenApparatus (2026), CC BY 4.0.

## Hardware

The OpenApparatus hardware retains its [CERN-OHL-W-2.0 license](https://github.com/jsxliu/lenz-law-visualizer/blob/main/LICENSE).
The animation uses the original end-cap mesh at millimeter scale.

- [Dual-tube design and build guide](https://github.com/jsxliu/lenz-law-visualizer/tree/main/designs/dual-tube-design)
- [Original end-cap mesh](https://github.com/jsxliu/lenz-law-visualizer/blob/main/designs/dual-tube-design/parts/cap_lenz_visualizer_v2.stl)

## Physics

Field and fall calculations use the
[Derby–Olbert reproduction](https://github.com/jsxliu/derby-olbert-2010).
Apparatus geometry, cap stops, and the free-fall control are additions for this animation.

Derby, Norman, and Stanislaw Olbert (2010). “Cylindrical magnets and ideal
solenoids.” *American Journal of Physics*, 78(3), 229–235.
[DOI: 10.1119/1.3256157](https://doi.org/10.1119/1.3256157).

Copper and magnet inputs are adapted from Jonathan Liu's physics-class report,
“A Review and Independent Study of Magnetic Braking in Conducting Tubes.”
See [simulation parameters and assumptions](scenario.md) for this animation's configuration.

## Tools

Rendering: Three.js 0.169.0 and its STL loader
([MIT](https://github.com/mrdoob/three.js/blob/r169/LICENSE)).
Numerical computation: NumPy and SciPy.

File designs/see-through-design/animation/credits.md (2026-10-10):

# Animation credits and licenses

© 2026 Jonathan Liu / OpenApparatus.

See the project-wide
[AI assistance](https://github.com/jsxliu/lenz-law-visualizer#ai-assistance).

## Presentation

Original text, video, poster, and synthesized landing sounds:
[CC BY 4.0](LICENSE-media). Viewer HTML/CSS:
[MIT](LICENSE-viewer). The sounds are illustrative contact cues, not measured acoustics.

Suggested attribution:

> “See-through animation” by Jonathan Liu / OpenApparatus (2026), CC BY 4.0.

## Hardware

The OpenApparatus hardware retains its
[CERN-OHL-W-2.0 license](https://github.com/jsxliu/lenz-law-visualizer/blob/main/LICENSE).
The animation depicts the prototype dimensions and uses its end-cap mesh at
millimeter scale. Stop planes for timing are specified separately in
[scenario.md](scenario.md).

- [See-through design and build guide](https://github.com/jsxliu/lenz-law-visualizer/tree/main/designs/see-through-design)
- [Original end-cap mesh](https://github.com/jsxliu/lenz-law-visualizer/blob/main/designs/see-through-design/parts/see_through_design_end_cap_v1.stl)
- [Original control-ring print file](https://github.com/jsxliu/lenz-law-visualizer/blob/main/designs/see-through-design/parts/free_fall_ring_v1.stl)

## Physics

The cylindrical-magnet field calculation is based on the MIT-licensed
[Derby–Olbert reproduction](https://github.com/jsxliu/derby-olbert-2010).
The simulation adapts this field to the annular geometry and includes the
finite copper length and full radial wall integral to determine the magnet
trajectory. The matching nonmagnetic control uses analytic free fall.

Derby, Norman, and Stanislaw Olbert (2010). “Cylindrical magnets and ideal
solenoids.” *American Journal of Physics*, 78(3), 229–235.
[DOI: 10.1119/1.3256157](https://doi.org/10.1119/1.3256157).

Material inputs use conductivity and nominal remanence from the
[dual-tube scenario](https://github.com/jsxliu/lenz-law-visualizer/blob/main/designs/dual-tube-design/animation/scenario.md)
and magnet density 7850 kg/m³. See [simulation parameters and assumptions](scenario.md).

## Tools

Rendering: Three.js 0.169.0 and its STL loader
([MIT](https://github.com/mrdoob/three.js/blob/r169/LICENSE)).
Numerical computation: NumPy and SciPy.

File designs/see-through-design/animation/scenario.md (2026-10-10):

# See-through simulation parameters and assumptions

The animation compares a ring magnet falling around the outside of a copper
tube with a matching nonmagnetic control ring. Both paths have identical copper
tubes and clear outer sleeves. The rings are released simultaneously from rest
and travel the same distance between stops.

## Simulation parameters

| Parameter | Value |
|---|---|
| Travel of each ring's center | 274.375 mm (10.802″) |
| Copper and clear tube lengths | 304.8 mm (12″) |
| Copper outside × inside diameter | 12.00 × 10.00 mm (0.472″ × 0.394″) |
| Copper wall thickness | 1.00 mm (0.039″) |
| Copper conductivity | 49.3 MS/m |
| Clear sleeve outside × inside diameter | 25.4 × 22.098 mm (1″ × 0.870″) |
| Magnet and control outside diameter × inside diameter × height | 19.05 × 12.70 × 9.525 mm (¾″ × ½″ × ⅜″) |
| Magnet density | 7850 kg/m³ |
| Magnet mass, from ring volume and density | 11.840 g |
| Magnet nominal remanence | 1.18 T |
| Stop contact plane inside each tube end | 10.45 mm (0.411″) |
| Gravity | 9.80665 m/s² |
| Initial velocity, both rings | 0 m/s |

The metric dimensions are the simulation inputs; inch equivalents are rounded.

## Predicted timing and presentation

Predicted arrival times after release are **1.004343 s** for the magnet and
**0.236552 s** for the control. These are numerical predictions using the
specified geometry and nominal material properties.

The animation is presented at 60 fps and 1440 × 900 pixels, with real-time
motion, a quarter-speed replay of the same trajectories, and a three-second
closing hold. Landing sounds mark each arrival; they are illustrative cues,
not simulated impact acoustics.

## Basic assumptions

- Both rings remain centered in upright tubes. Copper and clear tube ends
  are aligned, and the tubes remain fixed.
- The magnet is uniformly magnetized along its axis. Braking adapts the
  [Derby–Olbert reproduction](https://github.com/jsxliu/derby-olbert-2010)
  to the ring by subtracting the inner cylinder's field from the outer
  cylinder's field. The quasistatic calculation integrates over the finite
  copper length and through the full wall thickness.
- The control has the magnet's ring geometry and follows ideal free fall,
  independent of its mass. Airflow and pressure buildup are neglected.
- Material properties are constant. Rubbing, tilt, air resistance, eddy-current
  inductance, induced-field feedback, and magnet recoil permeability are neglected.
- Both rings stop without bouncing at stops inferred from the cap geometry.
  Actual assembled stop positions may differ.

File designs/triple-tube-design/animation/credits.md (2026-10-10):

# Animation credits and licenses

© 2026 Jonathan Liu / OpenApparatus.

See the project-wide
[AI assistance](https://github.com/jsxliu/lenz-law-visualizer#ai-assistance).

## Presentation

Original text, video, poster, and synthesized landing sounds:
[CC BY 4.0](LICENSE-media). Viewer HTML/CSS:
[MIT](LICENSE-viewer). The sounds are illustrative contact cues, not measured acoustics.

Suggested attribution:

> “Triple-tube animation” by Jonathan Liu / OpenApparatus (2026), CC BY 4.0.

## Hardware

The OpenApparatus hardware retains its
[CERN-OHL-W-2.0 license](https://github.com/jsxliu/lenz-law-visualizer/blob/main/LICENSE).
The animation depicts the triple-tube design and uses its original end-cap
mesh at millimeter scale. Stop positions and modeled dimensions are specified
in [scenario.md](scenario.md).

- [Triple-tube design and build guide](https://github.com/jsxliu/lenz-law-visualizer/tree/main/designs/triple-tube-design)
- [Original end-cap mesh](https://github.com/jsxliu/lenz-law-visualizer/blob/main/designs/triple-tube-design/parts/cap_triple_tube_design_v1.stl)
- [Optional control-cylinder print file](https://github.com/jsxliu/lenz-law-visualizer/blob/main/designs/triple-tube-design/parts/control_weight_cylinder_3D_print_v1.stl)

## Physics

Field and fall calculations use the MIT-licensed
[Derby–Olbert reproduction](https://github.com/jsxliu/derby-olbert-2010).
Both magnets use its finite-length, mean-wall-radius braking model. Apparatus
geometry, cap stops, and the analytic free-fall control are additions for the
animation.

Derby, Norman, and Stanislaw Olbert (2010). “Cylindrical magnets and ideal
solenoids.” *American Journal of Physics*, 78(3), 229–235.
[DOI: 10.1119/1.3256157](https://doi.org/10.1119/1.3256157).

Copper and magnet inputs follow the existing
[dual-tube scenario](https://github.com/jsxliu/lenz-law-visualizer/blob/main/designs/dual-tube-design/animation/scenario.md).
Aluminum geometry (6.78 mm inner radius and 1.22 mm wall) follows J Liu,
*A Review and Independent Study of Magnetic Braking in Conducting Tubes*
(September 29, 2026), §4.3, Table 3, page 4. The animation retains its
12-inch tube length and 25 MS/m aluminum conductivity; it does not adopt
the report's five-foot length or 24 MS/m conductivity.

Aluminum conductivity follows Kaiser Aluminum's typical **6061-T6** value in
[Soft Alloy Tube & Pipe, Alloy 6061 physical properties, PDF page 13](https://online.kaiseraluminum.com/depot/PublicProductInformation/Document/1011/Kaiser_Aluminum_Soft_Alloy_Tube.pdf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).
See [simulation parameters and assumptions](scenario.md) for the inputs and
the three-path configuration.

## Tools

Rendering: Three.js 0.169.0 and its STL loader
([MIT](https://github.com/mrdoob/three.js/blob/r169/LICENSE)).
Numerical computation: NumPy and SciPy.

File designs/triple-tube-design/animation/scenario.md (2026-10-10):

# Triple-tube simulation parameters and assumptions

The animation compares matching cylindrical magnets falling inside copper
and aluminum tubes with a nonmagnetic control in the clear center tube.
All three objects are released simultaneously from rest and travel the same
distance between stops.

## Simulation parameters

| Parameter | Value |
|---|---|
| Travel of each object's center | 303.42 mm (11.946″) |
| All modeled tube lengths | 304.8 mm (12″) |
| Copper outside × inside diameter | 15.90 × 13.82 mm (0.626″ × 0.544″) |
| Copper wall thickness | 1.04 mm (0.041″) |
| Copper conductivity | 49.3 MS/m |
| Aluminum outside × inside diameter | 16.00 × 13.56 mm (0.630″ × 0.534″) |
| Aluminum wall thickness | 1.22 mm (0.048″) |
| Aluminum conductivity | 25.0 MS/m (nominal 6061-T6) |
| Clear tube outside × inside diameter | 15.875 × 12.700 mm (⅝″ × ½″) |
| Clear tube wall thickness | 1.5875 mm (1/16″) |
| Each magnet and control diameter × height | 12.64 × 25.38 mm (0.498″ × 0.999″) |
| Each magnet mass | 25 g |
| Each magnet nominal remanence | 1.18 T |
| Stop extension beyond each tube end | 12 mm (0.472″) |
| Gravity | 9.80665 m/s² |
| Initial velocity, all three objects | 0 m/s |

The metric dimensions are the simulation inputs; inch equivalents are rounded.
The simulated aluminum wall is thicker than the build guide's 0.035″ stock.
See [credits](credits.md) for the geometry and material sources.

## Predicted timing and presentation

Predicted arrival times after release are **2.738122 s** for the copper magnet,
**1.673317 s** for the aluminum magnet, and **0.248758 s** for the control.
These are numerical predictions using the specified geometry and nominal
material properties. The two magnet times reflect both conductivity and tube geometry.

The animation is presented at 60 fps and 1440 × 900 pixels, with real-time
motion, a quarter-speed replay of the same trajectories, and a three-second
closing hold. Landing sounds mark each arrival; they are illustrative cues,
not simulated impact acoustics.

## Basic assumptions

- All objects remain centered in upright tubes.
- Each magnet is a finite cylinder, uniformly magnetized along its axis.
  Braking uses the
  [Derby–Olbert reproduction](https://github.com/jsxliu/derby-olbert-2010)
  with finite tube length and a quasistatic, mean-wall-radius approximation:
  wall resistance uses the specified thickness and conductivity, and the field
  is evaluated at the wall's mean radius.
- The magnet paths are calculated independently; mutual magnet forces and
  magnetic coupling between tubes are neglected because of large spacing and insignificant induced friction.
- The control follows ideal free fall, independent of its mass. Its nominal
  radial clearance is 0.03 mm; rubbing, airflow, and pressure buildup are neglected.
- Material properties are constant. Tilt, rubbing, air resistance, eddy-current
  inductance, induced-field feedback, and magnet recoil permeability are neglected.
- All objects stop without bouncing at stops inferred from the cap geometry.
- Both metal cutaways are visual only; the modeled walls remain electrically intact.

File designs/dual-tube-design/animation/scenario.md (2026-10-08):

# Dual-tube simulation parameters and assumptions

The animation compares a cylindrical magnet falling inside a copper tube with
a matching nonmagnetic control falling inside a clear tube. Both objects are
released simultaneously from rest and travel the same distance between stops.

## Simulation parameters

| Parameter | Value |
|---|---|
| Travel of each object's center | 303.4 mm (11.945″) |
| Both modeled tube lengths | 304.78 mm (11.999″; nominal 12″) |
| Copper and clear tube outside diameter | 15.9 mm (0.626″) |
| Copper and clear tube inside diameter | 13.82 mm (0.544″) |
| Copper wall thickness | 1.04 mm (0.041″) |
| Copper conductivity | 49.3 MS/m |
| Magnet and control diameter × height | 12.64 × 25.38 mm (0.498″ × 0.999″) |
| Magnet mass | 25 g |
| Magnet nominal remanence | 1.18 T |
| Stop extension beyond each tube end | 12 mm (0.472″) |
| Gravity | 9.80665 m/s² |
| Initial velocity, both objects | 0 m/s |

The metric dimensions are the simulation inputs; inch equivalents are rounded.

## Predicted timing and presentation

Predicted arrival times after release are **2.737922 s** for the magnet and
**0.248750 s** for the control. These are numerical predictions using the
specified geometry and nominal material properties.

The animation is presented at 60 fps and 1440 × 900 pixels, with real-time
motion, a quarter-speed replay of the same trajectories, and a three-second
closing hold. Landing sounds mark each arrival; they are illustrative cues,
not simulated impact acoustics.

## Basic assumptions

- Both objects are released simultaneously from rest in upright tubes and remain centered.
- The magnet is a finite cylinder, uniformly magnetized along its axis.
  Braking uses the
  [Derby–Olbert reproduction](https://github.com/jsxliu/derby-olbert-2010)
  with finite tube length and a quasistatic, mean-wall-radius approximation:
  wall resistance uses the specified thickness and conductivity, and the field
  is evaluated at the wall's mean radius.
- For this ideal comparison, the clear tube is assigned the copper tube's
  dimensions, and the nonmagnetic control is assigned the magnet's dimensions.
- The control follows ideal free fall under gravity, independent of its mass.
  Airflow and pressure buildup in the clear tube are neglected.
- Material properties are constant. Rubbing, tilt, air resistance, eddy-current
  inductance, and induced-field feedback are neglected.
- Both objects stop without bouncing at lower stops inferred from the cap geometry.
- The copper cutaway is visual only; the modeled wall remains electrically intact.

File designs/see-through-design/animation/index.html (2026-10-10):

OpenApparatus · Jonathan Liu

# Watch magnetic braking happen.

A ring magnet falls around a copper tube beside a matching nonmagnetic control ring. Clear outer tubes keep both descents visible.

Your browser cannot play this video. Download the MP4.

The simulation adapts the cylindrical-magnet field from the Derby–Olbert reproduction on GitHub (https://github.com/jsxliu/derby-olbert-2010) to the ring geometry.

A simultaneous release, shown at real time and replayed at quarter speed. Sounds and visible labels mark each landing. Predicted arrivals: magnet 1.004 s; control 0.237 s.

## About the simulation

Both paths contain a copper tube inside a clear sleeve. Eddy currents in the copper slow the magnetic ring; the nonmagnetic control follows free fall.

The prototype uses a ¾″ OD × ½″ ID × ⅜″ high ring around 12 mm OD × 1 mm wall copper, with 12″ tubes. The model includes finite tube ends and integrates braking throughout the copper wall.

These are predictions for centered motion with nominal material properties and no rubbing. The timing uses stop planes inferred from the end-cap mesh; actual cap clearances and measured magnet strength can change the result.

© 2026 Jonathan Liu / OpenApparatus.

Hardware design and build guide (https://github.com/jsxliu/lenz-law-visualizer/tree/main/designs/see-through-design) · Media license · Viewer license

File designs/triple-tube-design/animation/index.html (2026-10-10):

OpenApparatus · Jonathan Liu

# Three paths. One release.

Matching magnets fall inside copper and aluminum tubes beside a nonmagnetic control. Compare how the two conductors slow the descent.

Your browser cannot play this video. Download the MP4.

Physics calculations use the open-source Derby–Olbert reproduction on GitHub (https://github.com/jsxliu/derby-olbert-2010).

A simultaneous release, shown at real time and replayed at quarter speed. Sounds and visible labels mark the predicted arrivals: control 0.249 s; aluminum magnet 1.673 s; copper magnet 2.738 s.

## About the simulation

Eddy currents in the metal tubes oppose the magnets' motion. The matching nonmagnetic control follows free fall inside the clear center tube.

The design uses nominal ½″ diameter × 1″ long magnets and 12″ tubes. Aluminum uses the physics report's 16.00 mm OD × 1.22 mm wall (0.62992″ OD × 0.04803″ wall), overriding the build guide's thinner aluminum stock. Conductivity remains 25 MS/m; copper dimensions match the dual-tube animation. The calculation includes finite tube ends.

Predictions assume centered motion, independent magnet paths, and nominal material properties. Both metal cutaways are visual only; the model assumes electrically intact walls. Actual magnet strength, fit, venting, and cap clearances can change the observed times.

© 2026 Jonathan Liu / OpenApparatus.

Hardware design and build guide (https://github.com/jsxliu/lenz-law-visualizer/tree/main/designs/triple-tube-design) · Media license · Viewer license

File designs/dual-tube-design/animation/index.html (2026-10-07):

OpenApparatus · Jonathan Liu

# One release. Two different falls.

A physics-based comparison: a magnet falls through copper tube beside a nonmagnetic control weight in a clear tube.

Your browser cannot play this video. Download the MP4.

Physics calculations use the open-source Derby–Olbert reproduction on GitHub (https://github.com/jsxliu/derby-olbert-2010).

A simultaneous release, shown at real time and replayed at quarter speed. Sounds and visible labels mark each landing. Predicted arrivals: magnet 2.738 s; control 0.249 s.

## About the simulation

Eddy currents in the copper tube slow the magnet. The cutaway reveals its motion; the modeled copper tube wall remains electrically intact.

This fixed configuration simulation predicts the falls from nominal material properties and the specified geometry.

© 2026 Jonathan Liu / OpenApparatus.

Hardware design and build guide (https://github.com/jsxliu/lenz-law-visualizer/tree/main/designs/dual-tube-design) · Media license · Viewer license

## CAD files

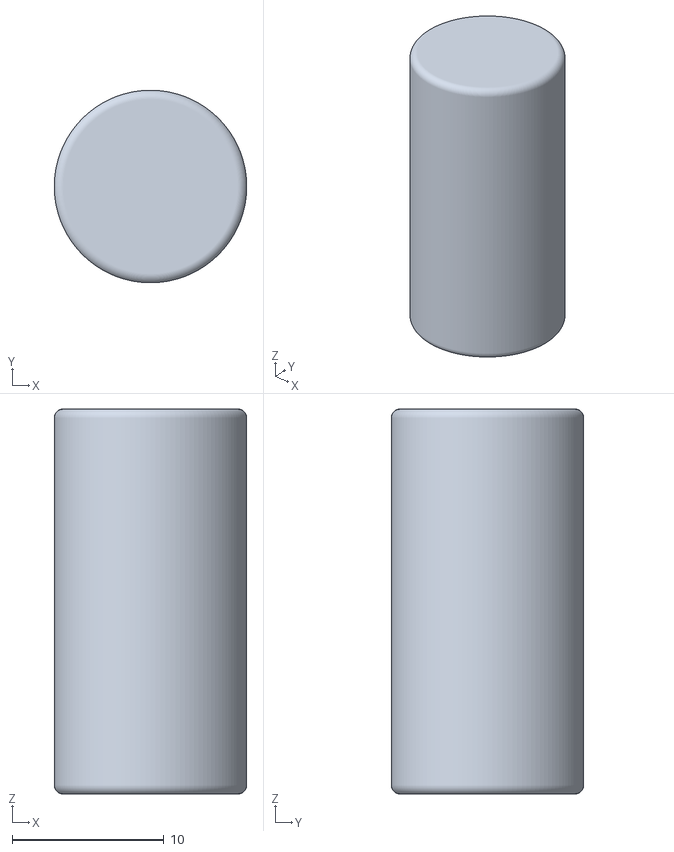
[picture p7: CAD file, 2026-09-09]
designs/dual-tube-design/parts/control_weight_cylinder_3D_print_v1.stl
12.7 x 12.7 x 25.4

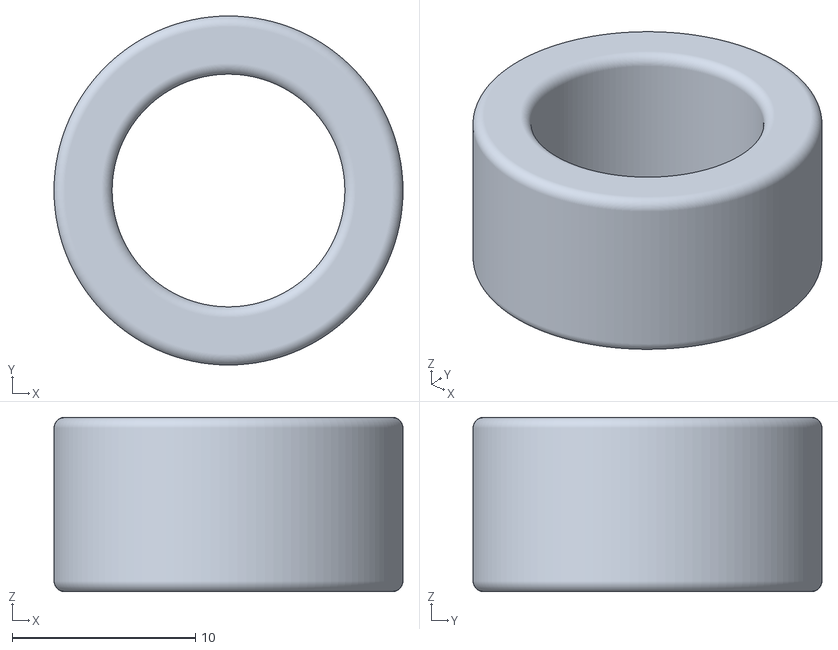
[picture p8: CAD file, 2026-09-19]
designs/see-through-design/parts/free_fall_ring_v1.stl
19.0 x 19.0 x 9.52

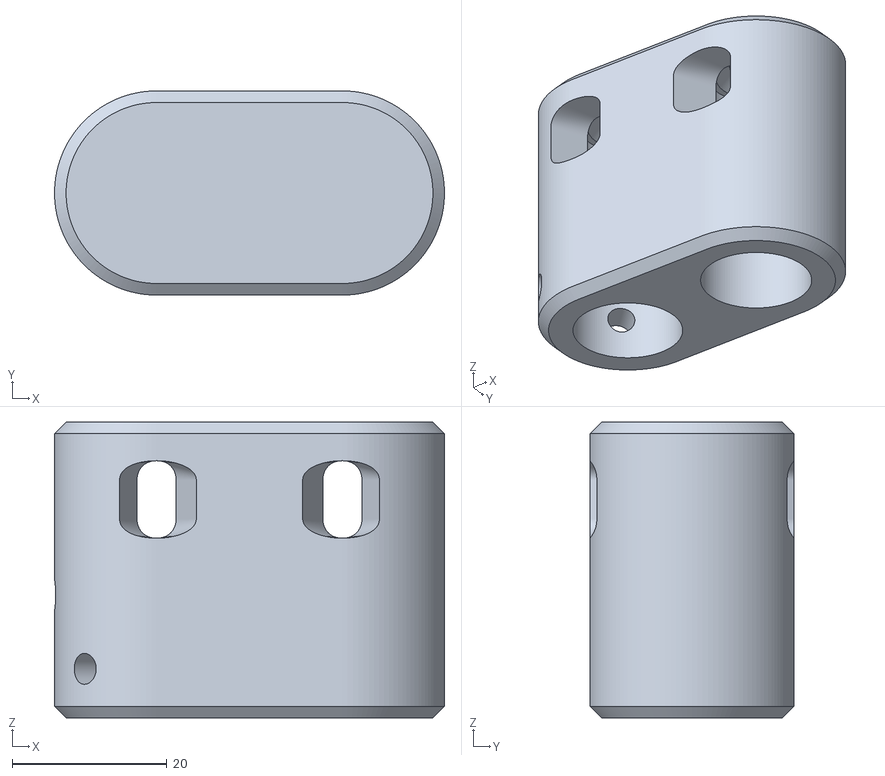
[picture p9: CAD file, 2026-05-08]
designs/dual-tube-design/parts/cap_lenz_visualizer_v2.stl
50.4 x 26.4 x 38.2

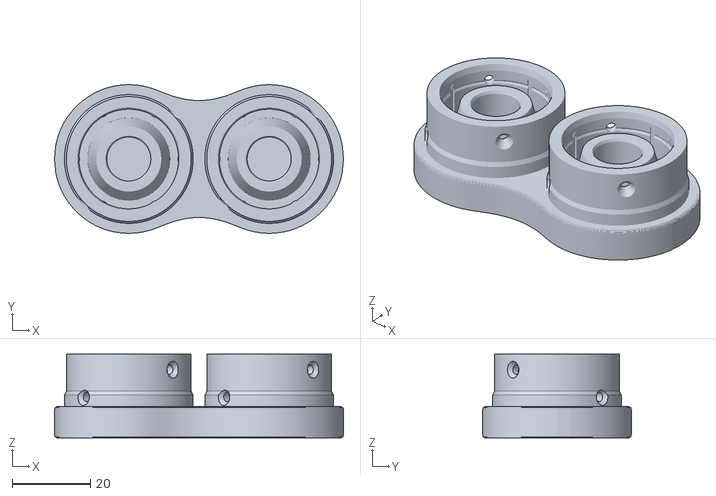
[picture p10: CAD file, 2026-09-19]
designs/see-through-design/parts/see_through_design_end_cap_v1.stl
74.1 x 38.1 x 21.5

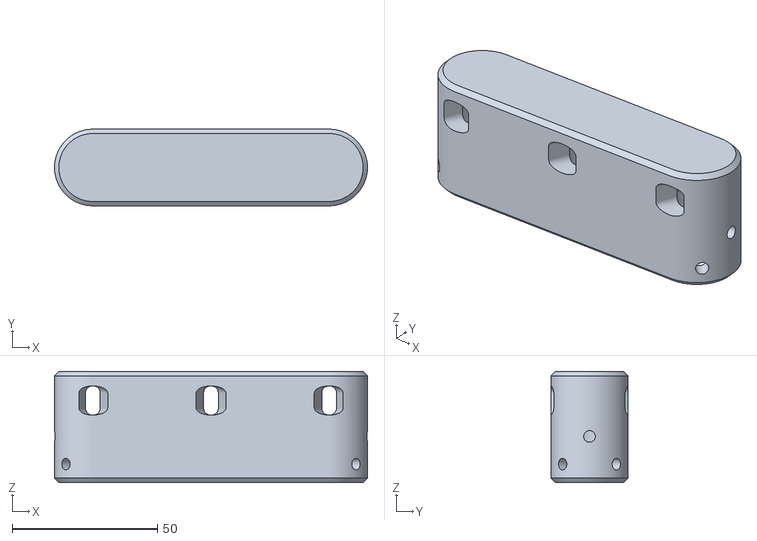
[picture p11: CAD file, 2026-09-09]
designs/triple-tube-design/parts/cap_triple_tube_design_v1.stl
107.7 x 26.4 x 38.2

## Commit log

2026-03-20 Initial Release: v1.0.0 Dual-Tube Lenz-Law Visualizer (CERN-OHL-W-2.0)
    [cap_lenz_visualizer_v1.stl]
2026-05-08 Optimized cap design: Larger viewing window and streamlined assembly.
    [cap_lenz_visualizer_v1.stl, cap_lenz_visualizer_v2.stl]
2026-09-09 Add triple-tube v1 design and reorganize project files
    [cap_lenz_visualizer_v2.stl, cap_triple_tube_design_v1.stl, control_weight_cylinder_3D_print_v1.stl]
2026-09-19 Add see-through v1 design
    [free_fall_ring_v1.stl, see_through_design_end_cap_v1.stl]
2026-09-19 Added See-Through hero image to landing page
2026-10-07 Refresh dual-tube animation layout and captions
    Enlarge the apparatus, update the clear-tube styling, and show imperial and metric dimensions with Design and Physics credits. Preserve the original trajectories and timing, and clarify the nominal-m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
2026-10-07 Revert "Refresh dual-tube animation layout and captions"
    This reverts commit 955f947f27ae37a6b16f60787e7f98613d7bd9b4.
2026-10-08 Update dual-tube animation layout and captions
2026-10-10 add animations for triple-tube and see-through designs
